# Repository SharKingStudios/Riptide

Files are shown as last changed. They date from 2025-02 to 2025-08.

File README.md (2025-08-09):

# Riptide – The Infinitely Expandable Keyboard

### My Massive Glowing Submission to Highway

---

## Renders
*Visuals because everyone loves eye candy.*

Final CAD Render Top
Final CAD Render Top Close
Final CAD Render Front Low
Final CAD Render Back
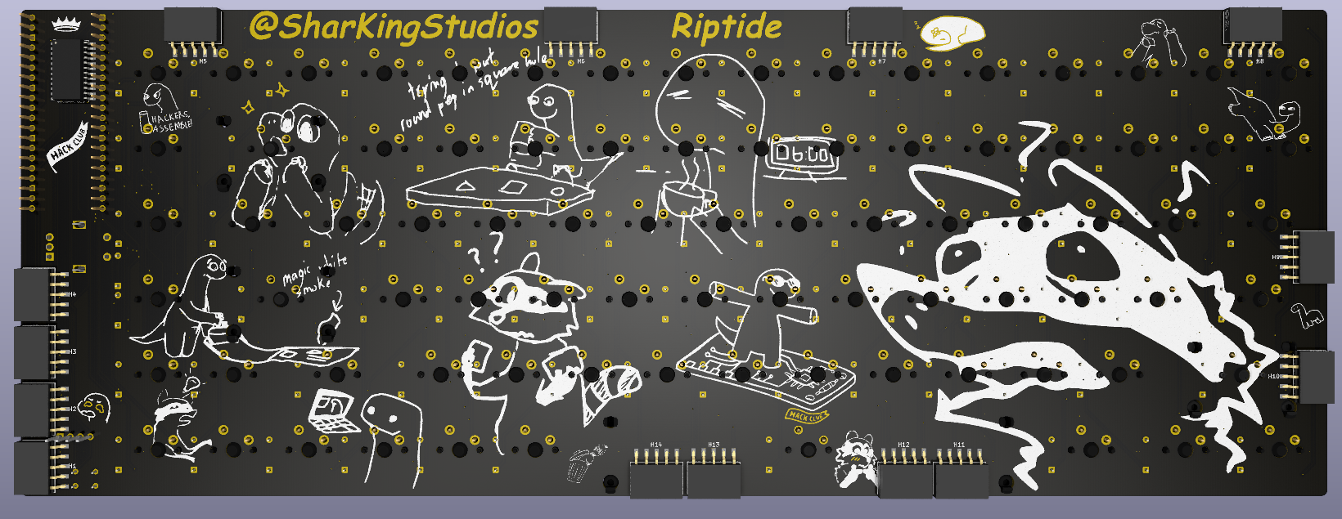
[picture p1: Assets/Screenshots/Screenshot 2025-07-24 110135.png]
Final PCB view back

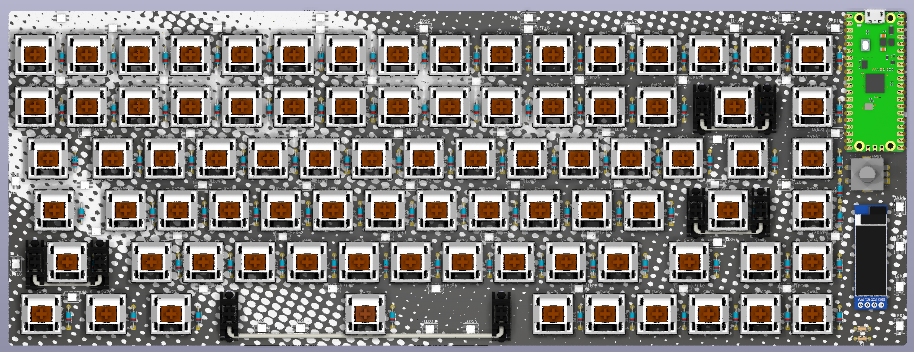
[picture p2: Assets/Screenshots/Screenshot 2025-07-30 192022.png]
Final PCB view top

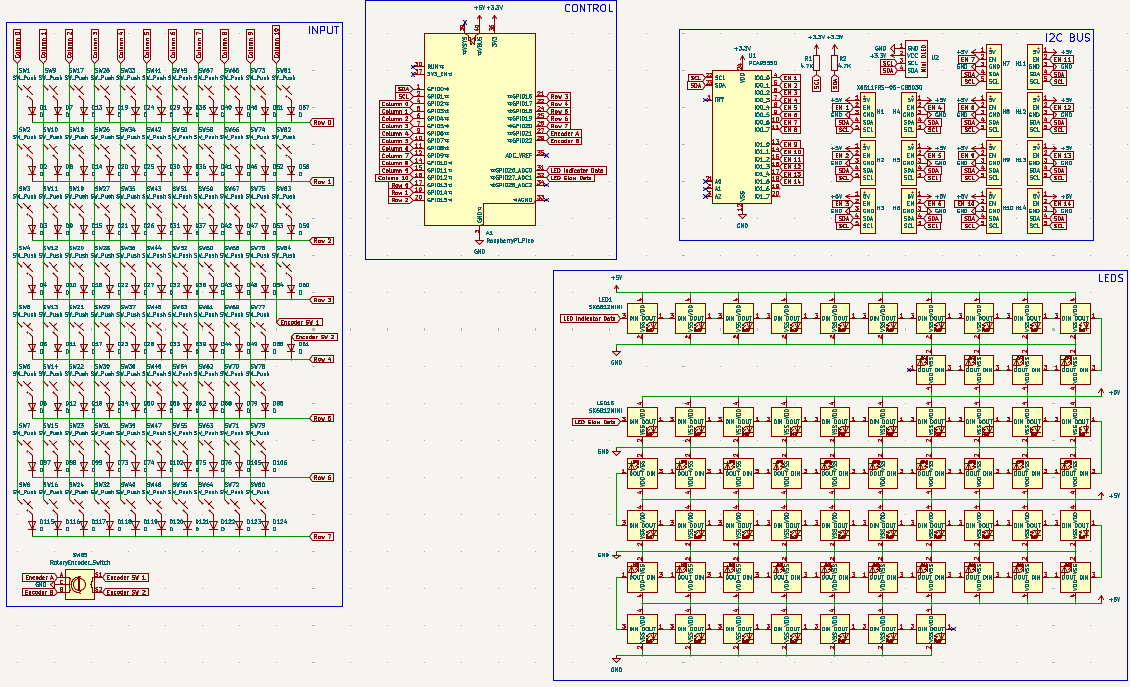
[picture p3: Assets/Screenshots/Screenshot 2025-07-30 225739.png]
Finished Schematic


---

## What is this?
It's a custom keyboard built for infinite expansion through its module ports! It uses an Orpheus Pico, QMK firmware, and even more LEDs.
The expansion modules could be literally anything! From a screen, a rechargeable battery, a buzzer, or even more LEDs! 

### Features:
- **Keycool84 Layout** – Possibly the best?
- **Rotary Encoder** – Twist for volume, scroll, or secret hacker functions.
- **Clickable Encoder Button** – Because sometimes, twisting isn’t enough.
- **61 SK6812 Mini LEDs** – ✨Almost blinding✨
- **Literally Infinite Expandability** – Custom designed module slots that support chaining submodules together!

---

## How It Works:
The infinitely expandable modules were built using an I2C bus! Also since the Orph Pico knows which modules are plugged in, certain modules could unlock further functionality from another! Like a button module being able to activate a haptic feedback (vibration) module. (This isnt built in yet // Software still WIP)

Each module slot has a 5V, EN, GND, SDA, and SCL lines.
After a module is plugged in and ready to work it will pull its EN line high to 3.3V, letting the Pico know there is something there in that expansion slot!

Final CAD Render Side

---

## Why?
I built this keyboard for [Highway](https://highway.hackclub.com)—an awesome Hack Club YSWS project mainly run by [Alex Ren](https://github.com/qcoral). (I helped run this event as one of the project reviewers!) I wanted to create something that wasnt just useful, but also super cool! Thats why I went with creating my own expansion support instead of just adding a USB hub and calling it a day.

---

## BOM
All the bits and pieces needed can be found **[here](/BOM.csv)**.

| Name | Amount | Price  | Source |
|---|---|---|---|
| PCB | 1 (5) | 33.74  | [JLCPCB](https://jlcpcb.com/) |
| Keycaps | 1 | 24.99  | [Amazon](https://www.amazon.com/dp/B0DBPKP52D?th=1) |
| Gateron Red Keyswitches| 1 | 34.99  | [Amazon](https://www.amazon.com/gp/product/B07CVQ7ZRL) |
| Gateron Clear Stabs | 1 | 11.99  | [Amazon](https://www.amazon.com/dp/B0BV2CKDJW) |
| Diodes | 85 (100) | 6.99 | [Amazon](https://www.amazon.com/dp/B079KJ91JZ) |
| 11"x14" Acrylic | 1 (2) | 11.99  | [Amazon](https://www.amazon.com/dp/B0CQYPRG4F) |
| SK6812MINI-E LEDs | 61 (65) | 3.84 | [LCSC](https://lcsc.com/product-detail/RGB-LEDs-Built-in-IC_OPSCO-Optoelectronics-SK6812MINI-E_C5149201.html) |
| PCA9555D | 1 | 1.75 | [LCSC](https://lcsc.com/product-detail/I-O-Expanders_NXP-PCA9555DB-118_C133183.html) |
| X6511FRS-05-C85D30 | 14 (15) | 2.46 | [LCSC](https://lcsc.com/product-detail/Female-Headers_XKB-Connection-X6511FRS-05-C85D30_C5142238.html) |
| 18ga Steel Plate | 1 | 0.00 | PRICE Industries |
| Orpheus Pico | 1 | 0.00 | Me |
| OLED | 1 | 0.00 | Old Hackpad Kit |
| EC11 Rotary Encoder | 1 | 0.00 | Old Hackpad Kit |
| M2.5 10mm Standoffs | 12 | 0.00 | Me |
| M2.5 3mm Screw | 12 | 0.00 | Me |
| 4.7K THT Resistor | 2 | 0.00 | Me |
| Shipping | N/A | 11.26  | LCSC |
| **Total** | — | **130.00** | — |

---

## Contribute  
Want to make it better? Open a PR, suggest a feature, or just yell at me on GitHub.

---

## Disclaimer  
This project is 100% free, open-source, and powered by **vibes**. If it breaks, explodes, or opens a black hole, **that’s on you.**

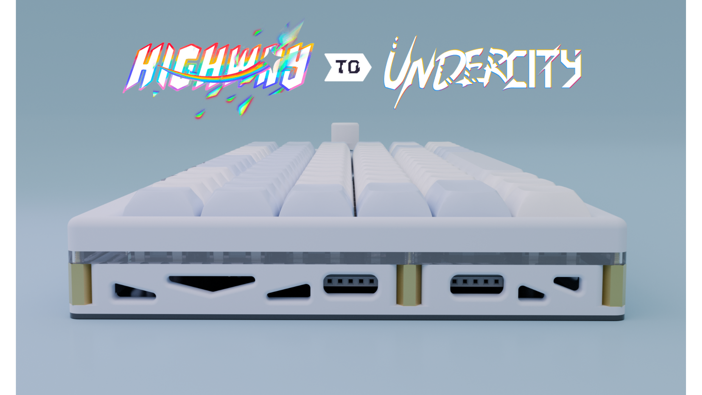
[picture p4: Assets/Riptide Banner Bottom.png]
Riptide Banner Bottom


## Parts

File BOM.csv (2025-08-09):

Name | Amount | Price | Source
PCB | 1 (5) | 33.74 | https://jlcpcb.com
Keycaps | 1 | 24.99 | https://www.amazon.com/dp/B0DBPKP52D
Gateron Red Keyswitches | 1 | 34.99 | https://www.amazon.com/gp/product/B07CVQ7ZRL
Gateron Clear Stabilizers | 1 | 11.99 | https://www.amazon.com/dp/B0BV2CKDJW
Diodes | 85 (100) | 6.99 | https://www.amazon.com/dp/B079KJ91JZ
11''x14'' Acrylic | 1 (2) | 11.99 | https://www.amazon.com/dp/B0CQYPRG4F
SK6812MINI-E LEDs | 61 (65) | 3.84 | https://lcsc.com/product-detail/RGB-LEDs-Built-in-IC_OPSCO-Optoelectronics-SK6812MINI-E_C5149201.html
PCA9555D | 1 | 1.75 | https://lcsc.com/product-detail/I-O-Expanders_NXP-PCA9555DB-118_C133183.html
X6511FRS-05-C85D30 | 14 (15) | 2.46 | https://lcsc.com/product-detail/Female-Headers_XKB-Connection-X6511FRS-05-C85D30_C5142238.html
18ga Steel Plate | 1 | 0 | PRICE Industries
Orpheus Pico | 1 | 0 | Me
OLED | 1 | 0 | Old Hackpad Kit
EC11 Rotary Encoder | 1 | 0 | Old Hackpad Kit
M2.5 10mm Standoffs | 12 | 0 | Me
M2.5 3mm Screw | 12 | 0 | Me
4.7K THT Resistor | 2 | 0 | Me
Shipping | N/A | 11.26 | LCSC
Total: |  | 130

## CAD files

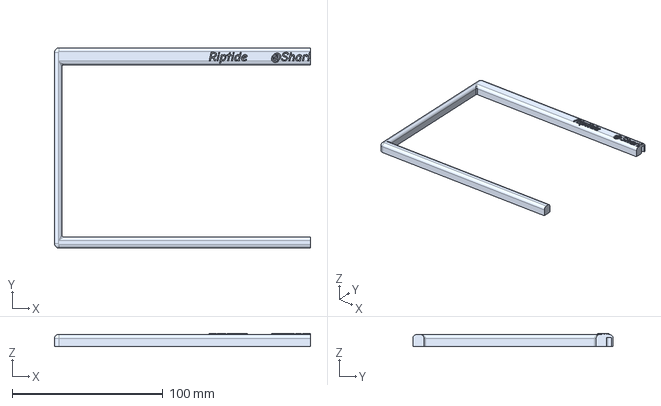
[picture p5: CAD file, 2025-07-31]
CAD/Individual Parts/Riptide Top Plate - Left.step
170.0 x 133.0 x 8.75 mm

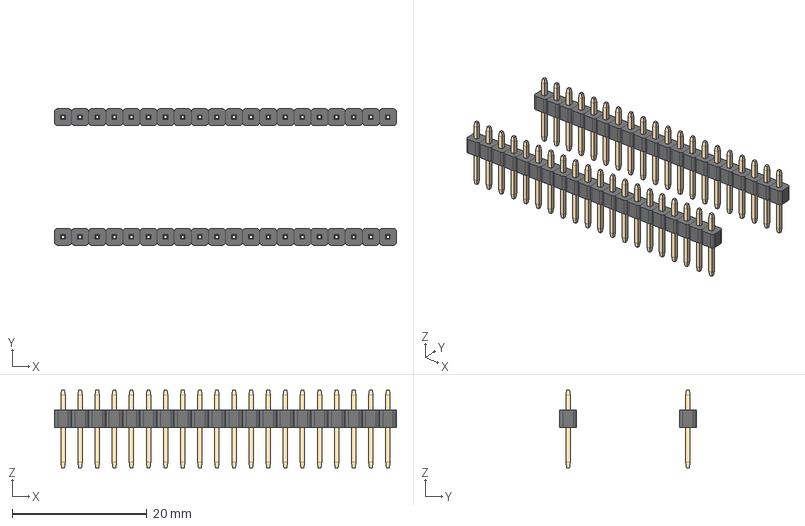
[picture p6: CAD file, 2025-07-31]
PCB/3D Models/pico headers.step
50.8 x 20.3 x 11.6 mm
spacer x 2
pins 21-40
pins 1-20

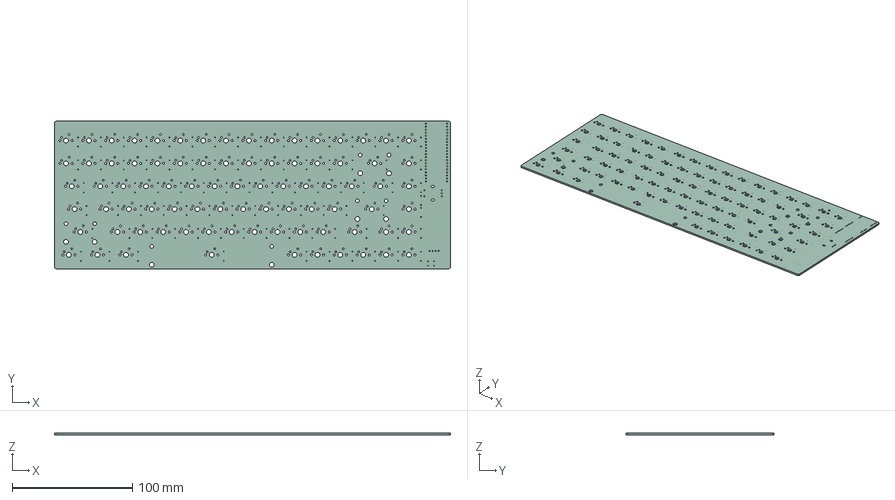
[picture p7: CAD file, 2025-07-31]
PCB/Riptide PCB Board Model v1.step
330.0 x 123.0 x 1.51 mm

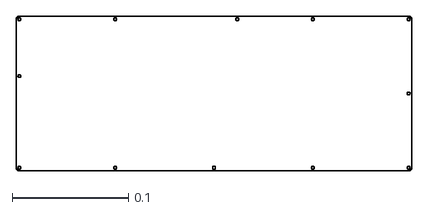
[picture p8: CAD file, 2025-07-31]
Production/Riptide Bottom Plate.dxf
0.34 x 0.133

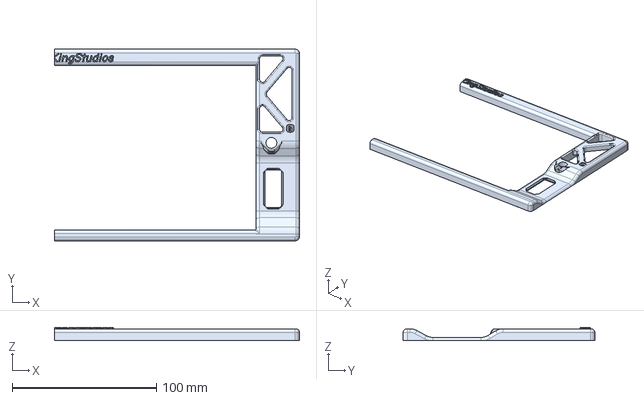
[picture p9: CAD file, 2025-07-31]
CAD/Individual Parts/Riptide Top Plate - Right.step
170.0 x 133.0 x 8.75 mm

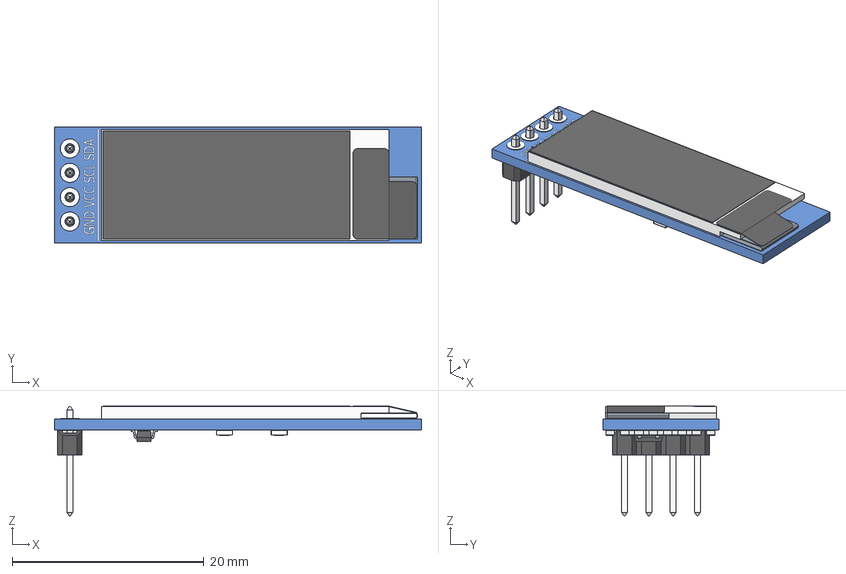
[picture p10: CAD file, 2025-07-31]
PCB/3D Models/OLED_0.91_128x32.stp
38.3 x 12.1 x 11.5 mm
OLED_0.91_128x32
Pin Header 4 x 1 TH 2.54mm Pitch
RESC-0603 x 13
2SD0601A

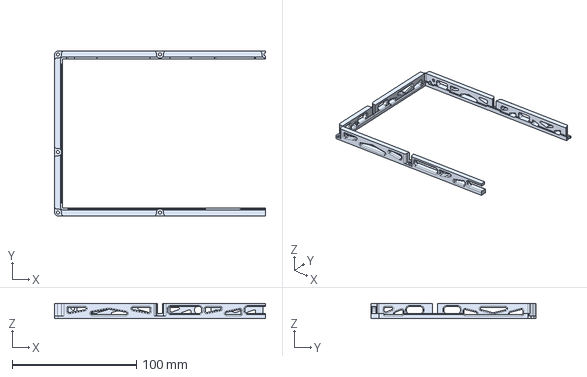
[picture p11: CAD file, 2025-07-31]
Production/Riptide Bottom Wall - Left.step
170.0 x 133.0 x 12.0 mm

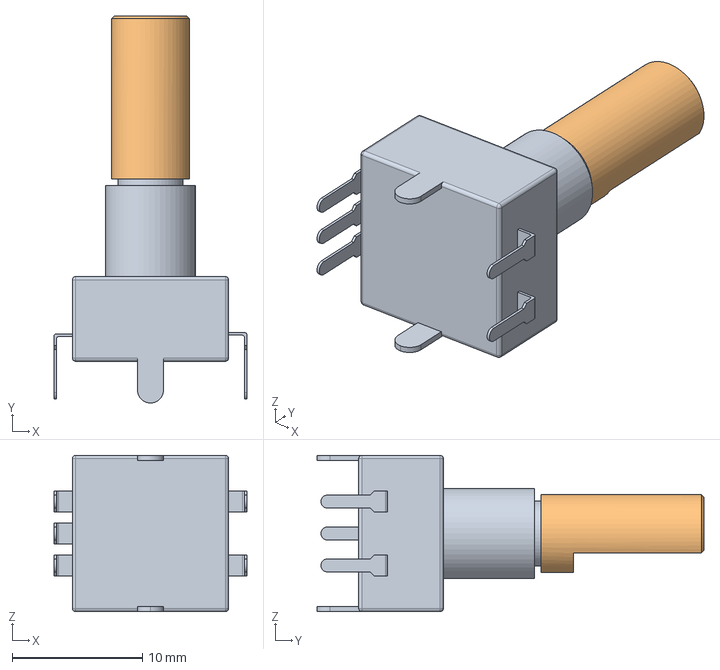
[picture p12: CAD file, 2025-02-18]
PCB/3D Models/RotaryEncoder_Alps_EC11E-Switch_Vertical_H20mm.step
14.8 x 29.7 x 12.0 mm

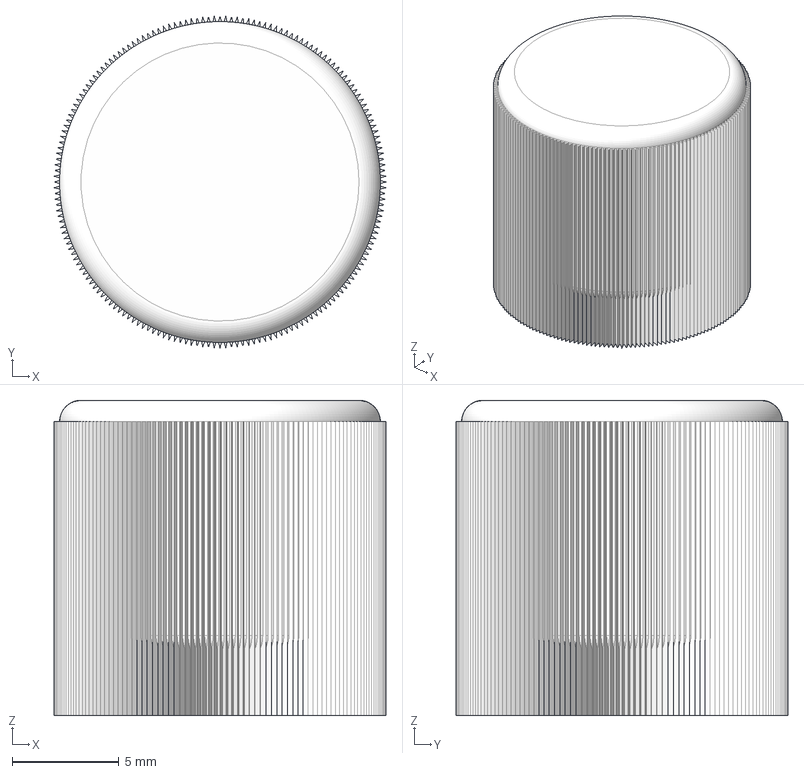
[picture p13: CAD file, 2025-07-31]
CAD/Individual Parts/Keyboard Knob.step
15.5 x 15.5 x 14.7 mm

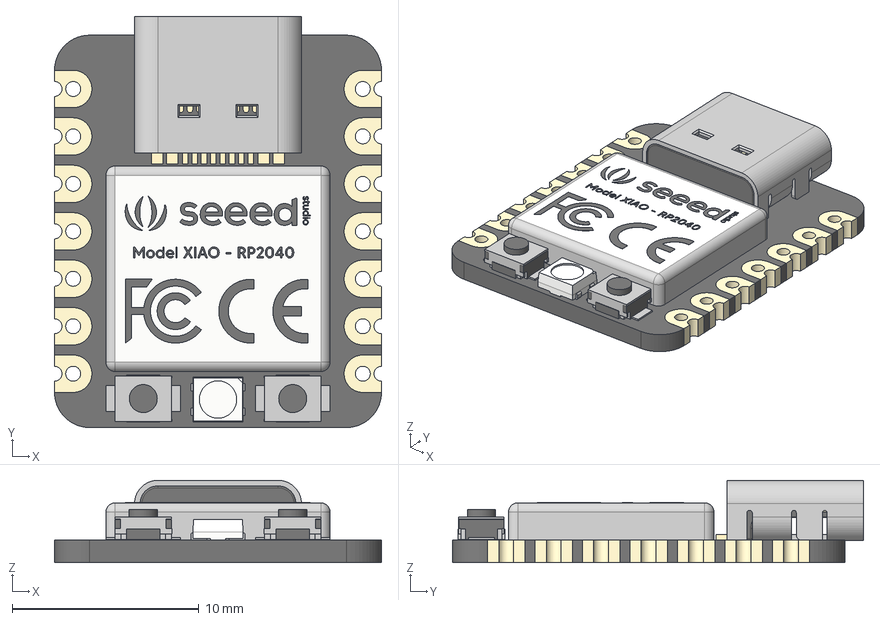
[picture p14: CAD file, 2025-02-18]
PCB/3D Models/Seeed_Studio_XIAO_RP2040_v26.step
17.5 x 22.0 x 4.40 mm
type-c v2
smd_button v3
DOUT
DIN
VSS
VDD
smd_button v3(Mirror)

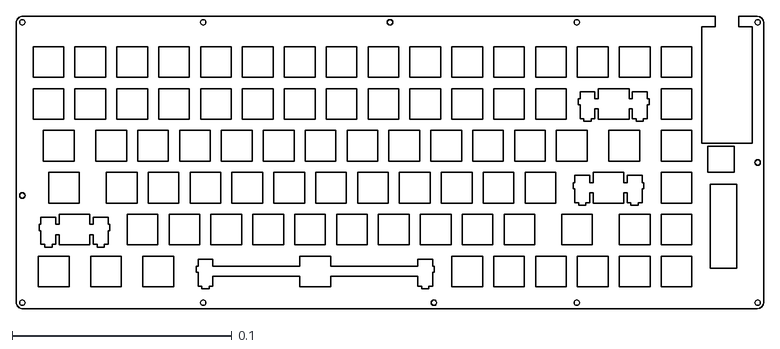
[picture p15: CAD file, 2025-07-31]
CAD/Individual Parts/Riptide Keyboard Plate.dxf
0.34 x 0.133

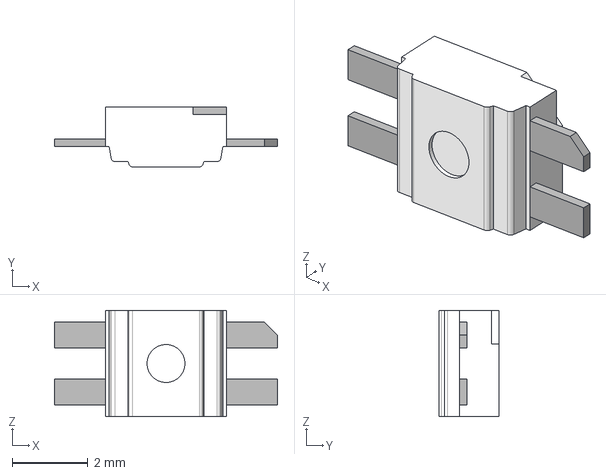
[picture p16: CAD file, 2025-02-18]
PCB/3D Models/SK6812MINI-E.step
5.88 x 1.58 x 2.80 mm

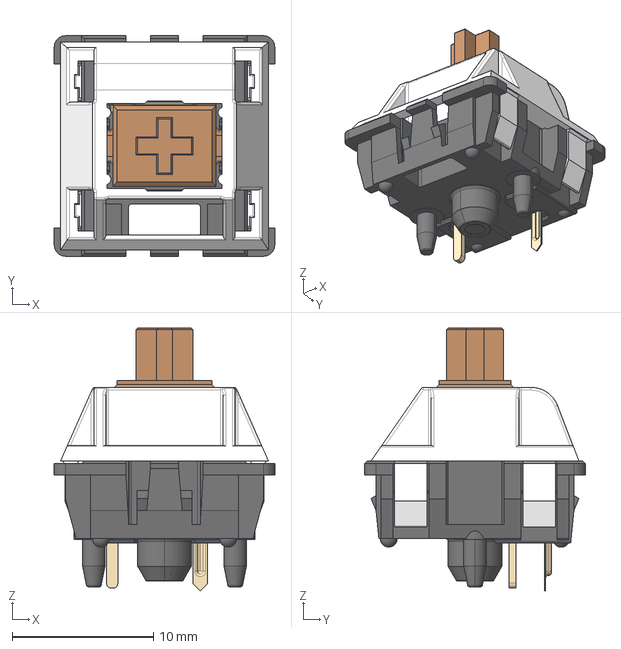
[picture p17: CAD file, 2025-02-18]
PCB/3D Models/MX_Switch.step
15.6 x 15.6 x 18.6 mm

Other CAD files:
Production/Riptide Bottom Wall - Right.step
CAD/Individual Parts/Riptide Bottom Wall - Right.step

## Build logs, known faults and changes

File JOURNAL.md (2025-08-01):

---
title: "Riptide"
author: "Logan Peterson"
description: "An Infinitely Expandable, Ocean Inspired Keyboard."
created_at: "2025-07-01"
---

**Total time Overall: 37h**

# June 1st: Started work on keyboard layout and matrix

Today I just researched a bit into the different keyboard layout types. I wanted to keep the layout similar as my current (membrane) keyboard.
I chose to use the Keycool84 layout as seen in the layout editor:

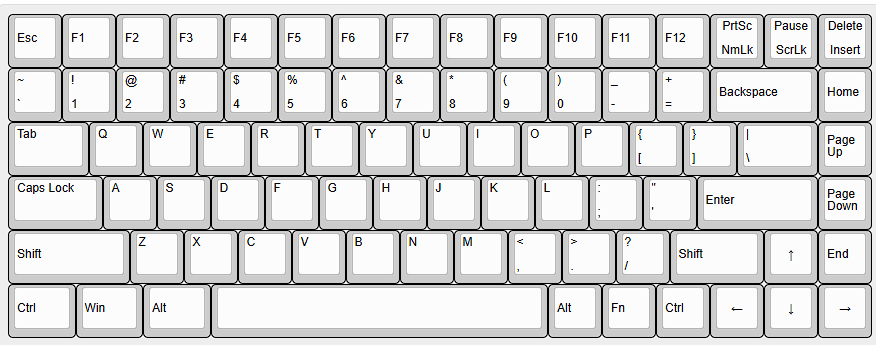
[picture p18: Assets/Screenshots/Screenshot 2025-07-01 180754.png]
Keycool84 layout


I also grabbed an old keyboard matrix I made when I was working on a keyboard prior to this. (This is about as far as I got lol)
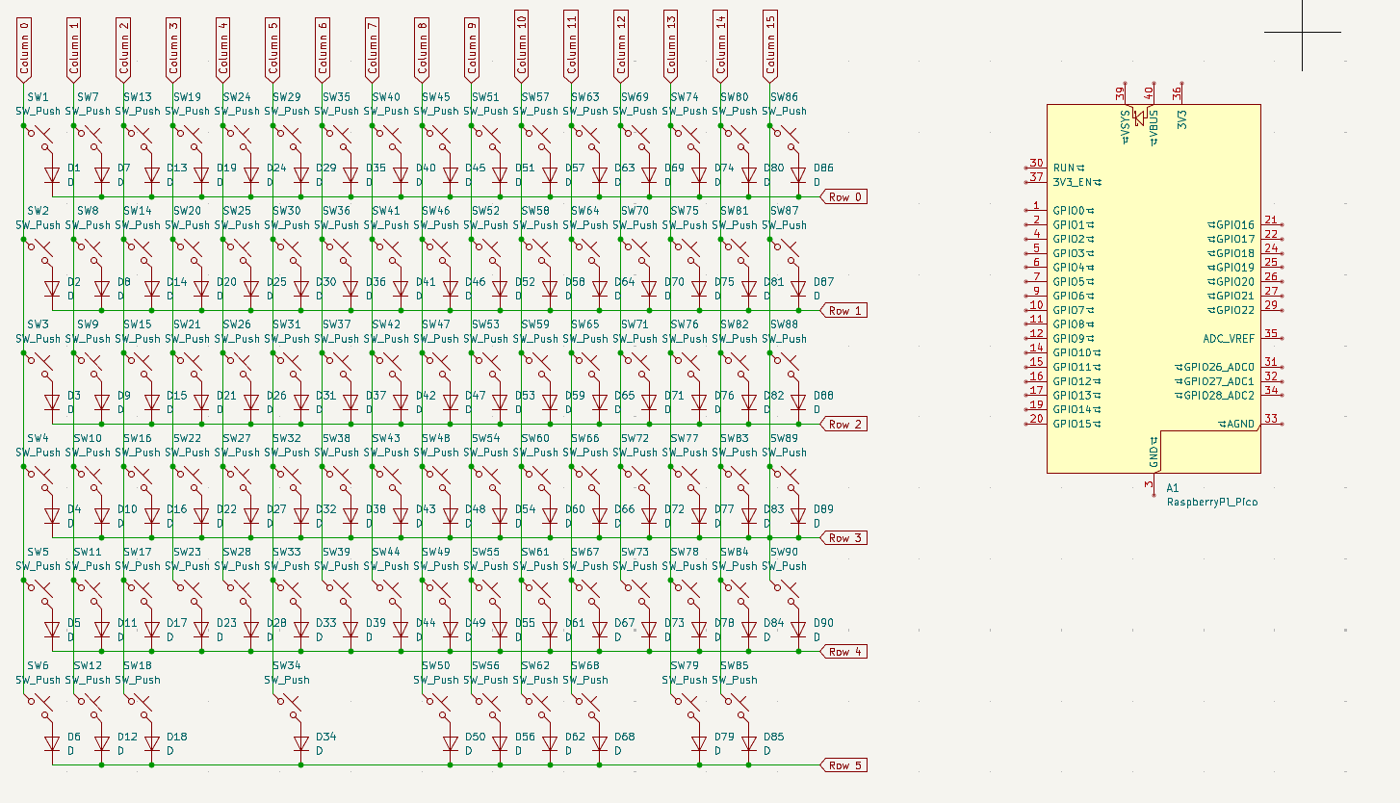
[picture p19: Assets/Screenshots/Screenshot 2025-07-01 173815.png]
old stuff


**Total time spent: 1h**

# June 2nd: Fixed the keyboard matrix

Today I fixed up the keyboard matrix to have it match my Keycool84 layout that I chose.
When I tried "fixing" it for the first time I actually added even more keys lol:

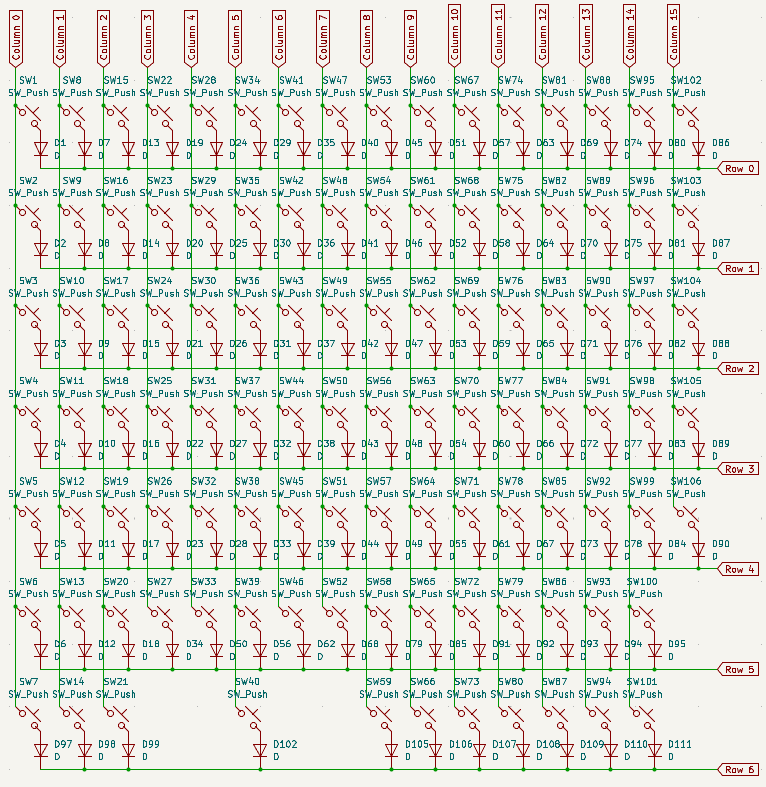
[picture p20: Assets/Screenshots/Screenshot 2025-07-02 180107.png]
not fixed lol


At first I was trying to create the keyboard matrix based of of the physical location of the keys.

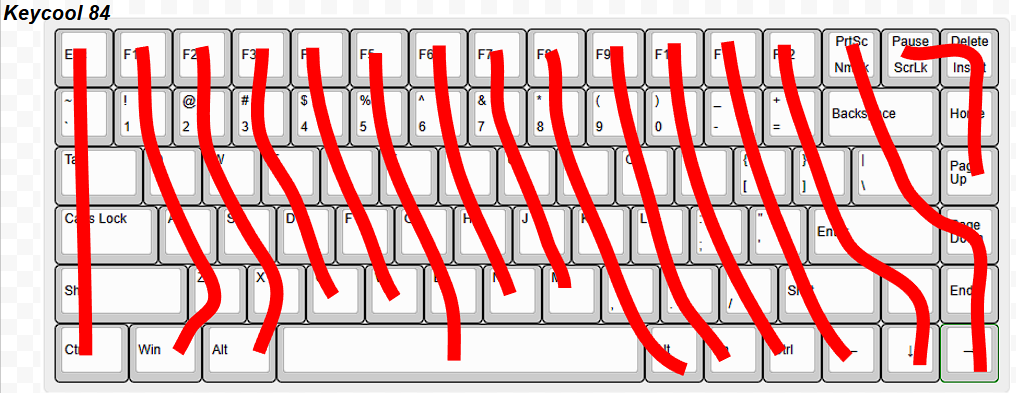
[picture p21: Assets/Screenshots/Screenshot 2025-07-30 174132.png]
Google drawings my beloved

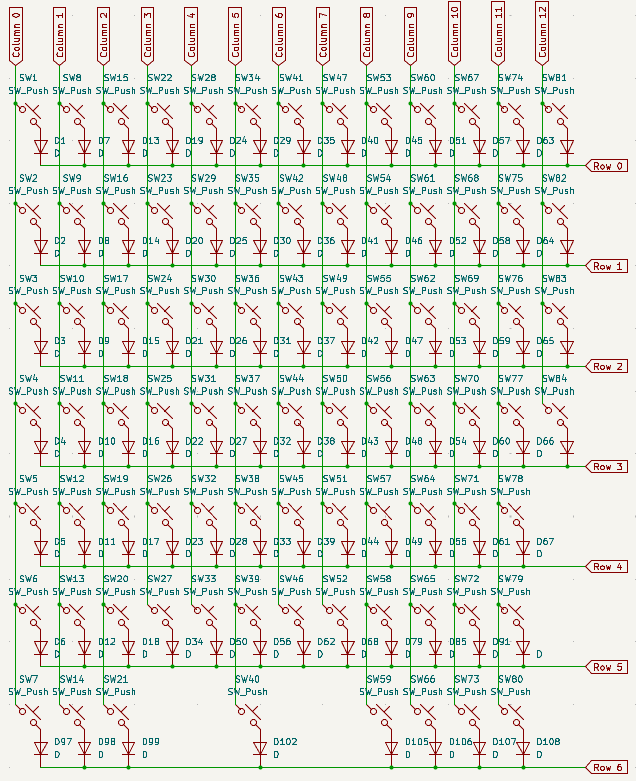
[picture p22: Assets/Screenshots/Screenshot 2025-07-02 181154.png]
Almost fixed


I then realized that since the keyboard layout editor would export the matrix data, I could make it much smaller.

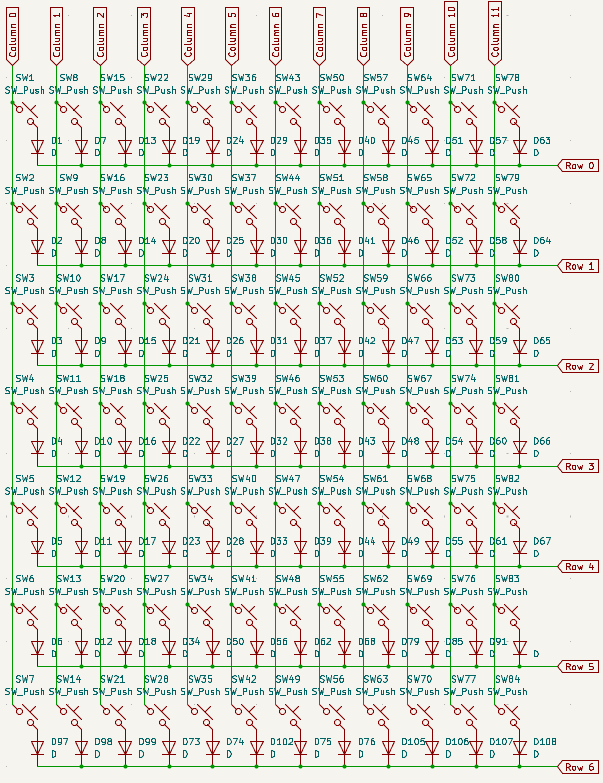
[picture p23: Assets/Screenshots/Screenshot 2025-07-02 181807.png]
Smol layout (11x8)


**Total time spent: 3h**

# June 3rd: LEDs and Infinite Expandability Support

Today I worked on putting together the LEDs in the schematic, wiring the pico to the keyboard matrix, as well as figuring out how I wanted to do the infinite expandability.

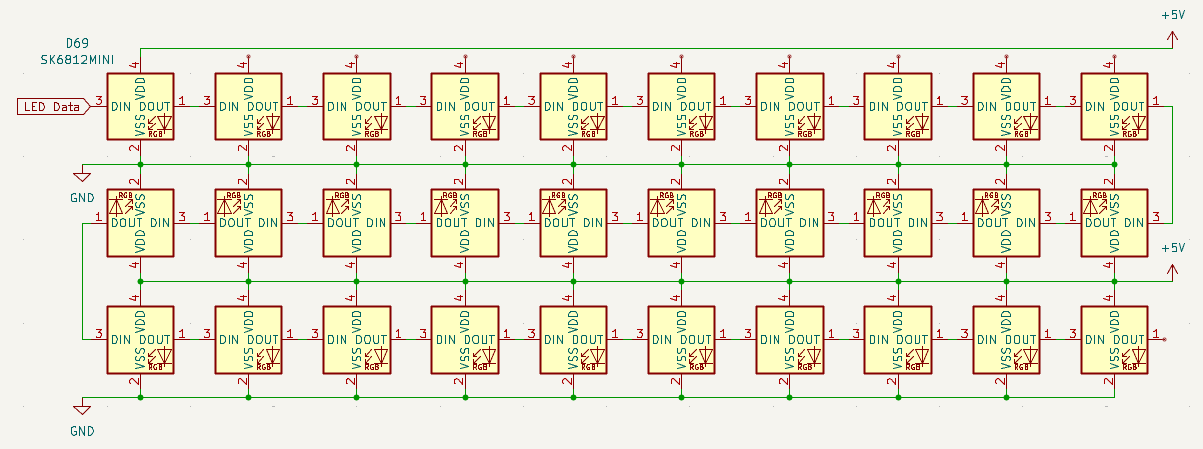
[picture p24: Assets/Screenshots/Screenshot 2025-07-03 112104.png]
LED Chain

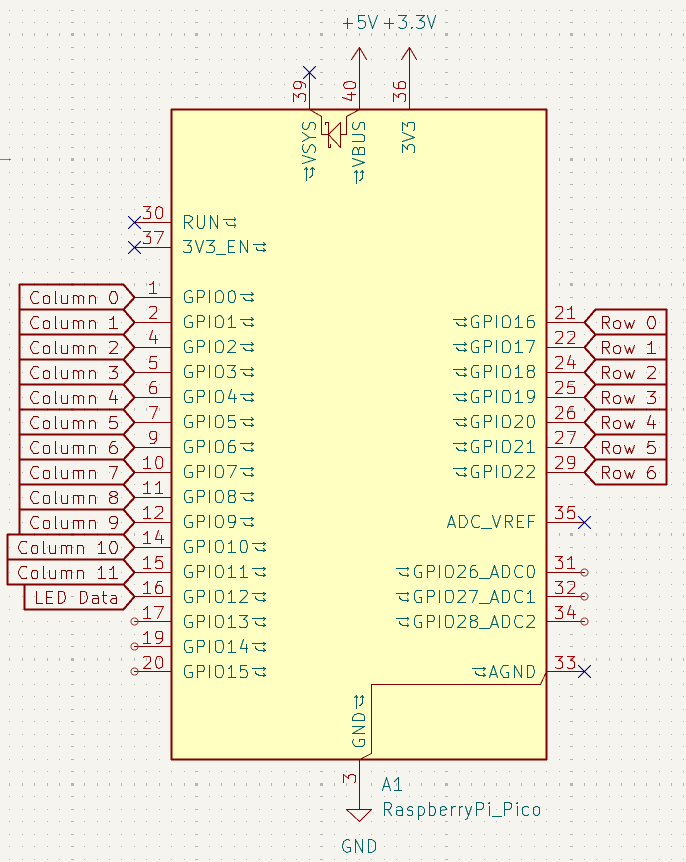
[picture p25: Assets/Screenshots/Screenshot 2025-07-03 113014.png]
Pico


So I want to have 5 pins for each module. 5V, EN, GND, SDA, SCL
I am planning on having the EN pin return 3.3V when the expansion module is ready. By having a EN pin for every module, I would be able to know which port I was plugging the module into. I am thinking this can give me some nice control and possibility for animations when you connect a module in a specific spot. (Like a wave emminating out from that port using the LEDs etc).
Anyways, the I2C bus seems like a fairly robust option considering you can use it with breadboard components, so it should be more then fine to route across my keyboard to the various module slots.

Since I would run out of GPIO pins if I gave the number connectors I wanted their own EN pin and since I already had an I2C bus, I decided to use a I2C GPIO expander to handle the EN pins. This also set my number of expansion slots at 16. (theres literally no reason to have this many lol // dear god I could put them in a matrix to have 64 slots)

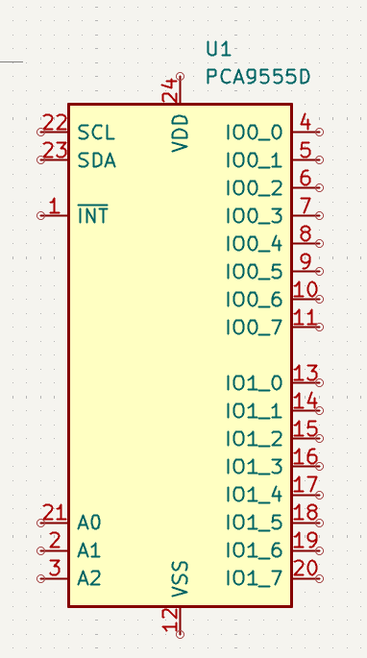
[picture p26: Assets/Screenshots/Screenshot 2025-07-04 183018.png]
I2C GPIO expander


**Time spent up to this point: 2h**

I then wanted to find a component that would work well for connecting the keyboard to the modules. I really wanted to have magnets integrated into the components to make hot swaps easier. While I could have used a 6 pin USB connector that would have looked pretty lame and someone would have plugged a USB drive into it hoping it would have worked. I actually spent a couple of hours on LCSC going through quite literally every single 5 pin 3 pin and 4 pin magnetic connector but all I found was this component here:

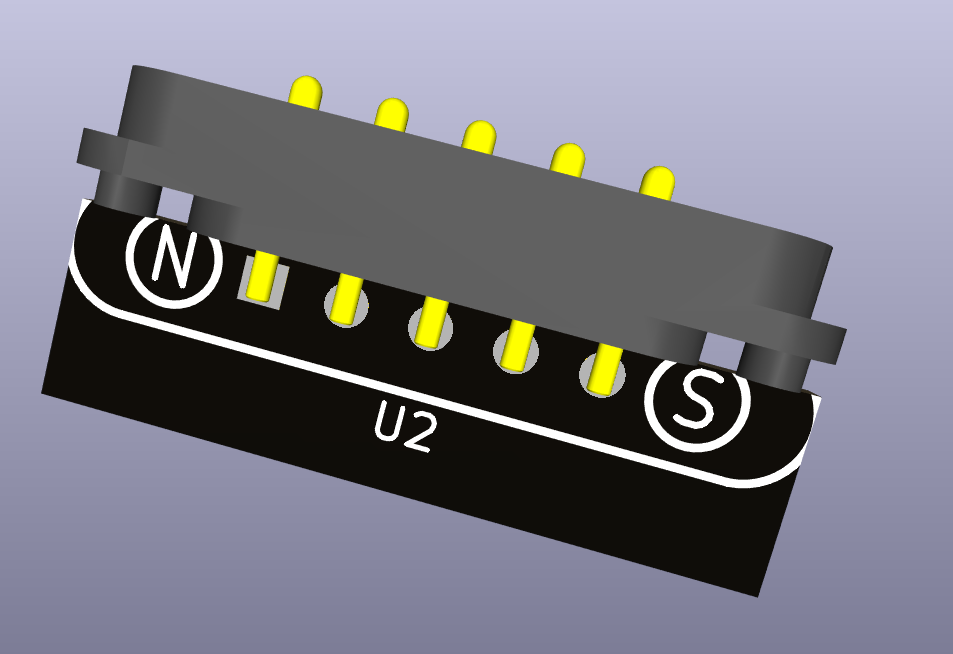
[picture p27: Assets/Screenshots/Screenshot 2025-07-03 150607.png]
Sketchy connector top view

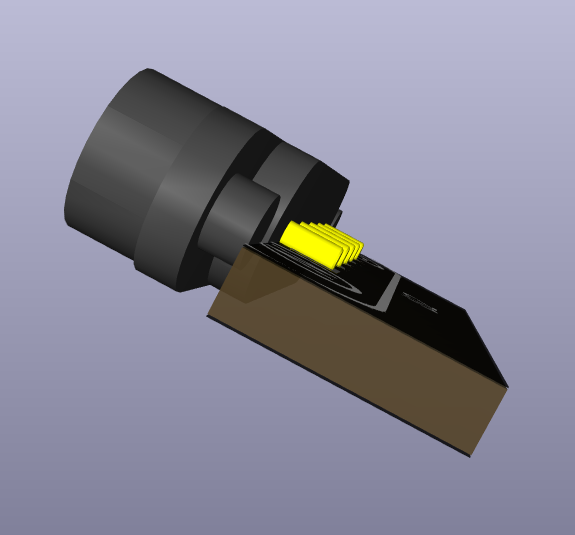
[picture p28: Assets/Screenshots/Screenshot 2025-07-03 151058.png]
Sketchy connector side view


(I manually rotated it onto its side)

Anyway I thought this would be too sketchy so I left that idea and went to the good ol reliable:

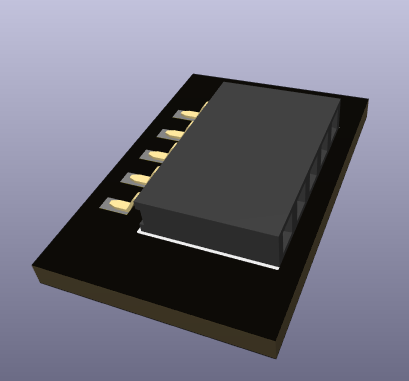
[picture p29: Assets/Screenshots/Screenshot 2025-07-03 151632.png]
Normal Female 2.54 header


After I figured out my connector footprint I put together a layout for my PCB (w.o. LEDs):

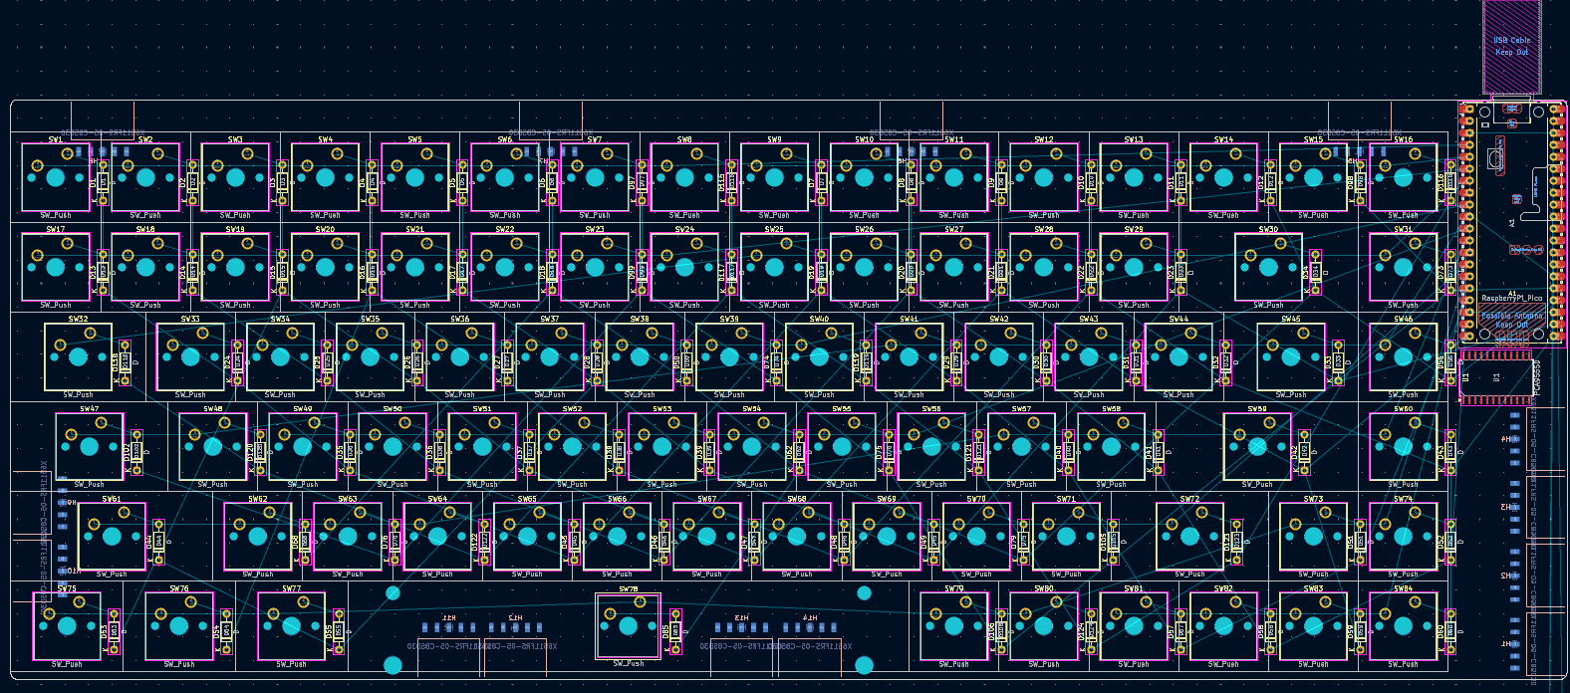
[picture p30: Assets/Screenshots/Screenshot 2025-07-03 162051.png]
Initial PCB layout


**Time wasted on connectors: 3h**

# June 5th: Laying out LEDs + Encoder and OLED

Today I layed out the LEDs into my PCB as well as adding an Encoder and an OLED.
I started the LED placement with the 14 LEDs that would act as status LEDs for any connected module:

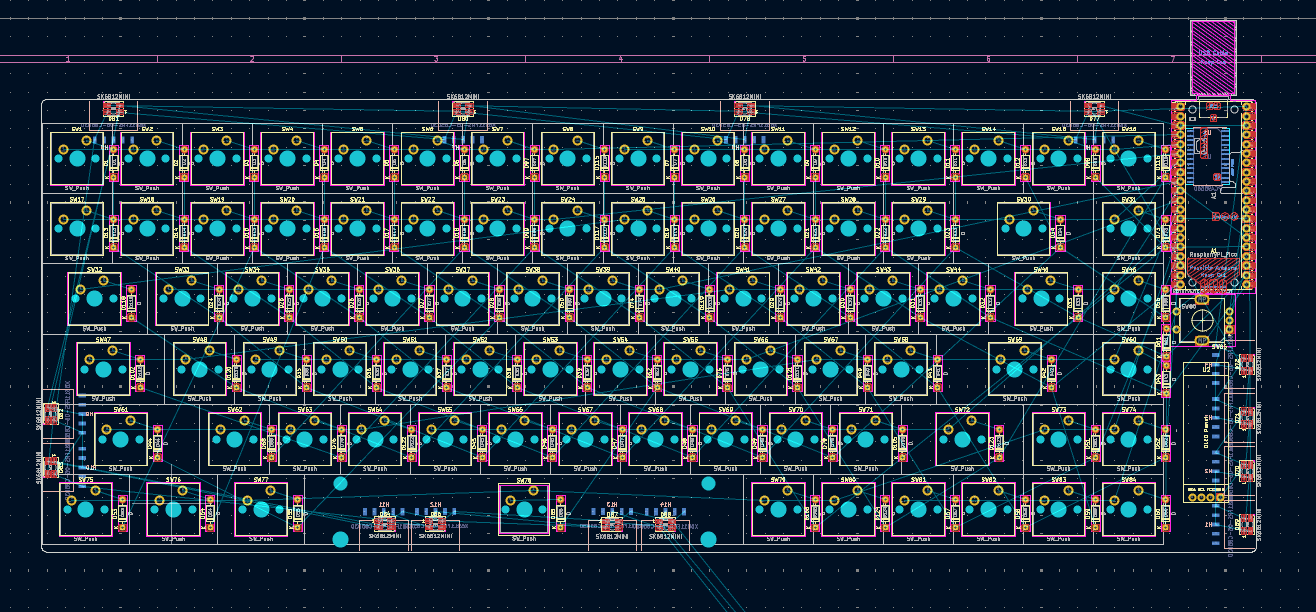
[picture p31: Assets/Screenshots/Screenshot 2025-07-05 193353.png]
Indicator LEDs in place


I also added even more LEDs that I would place around the keyboard and structured them into 2 data lines (I am hoping this makes programming the specifics easier).

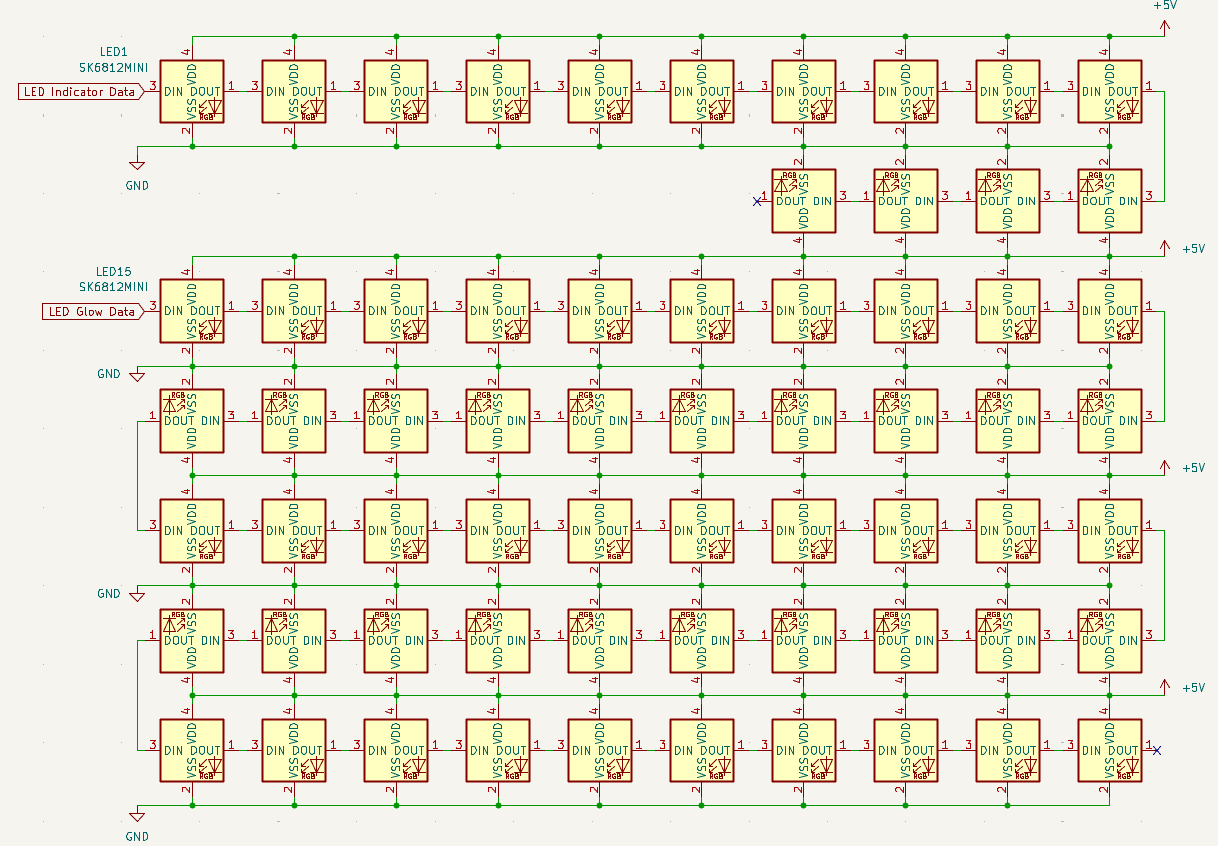
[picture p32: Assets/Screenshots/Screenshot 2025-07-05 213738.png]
Even more LEDs


After that I wired up all of the module slots in the schematic:

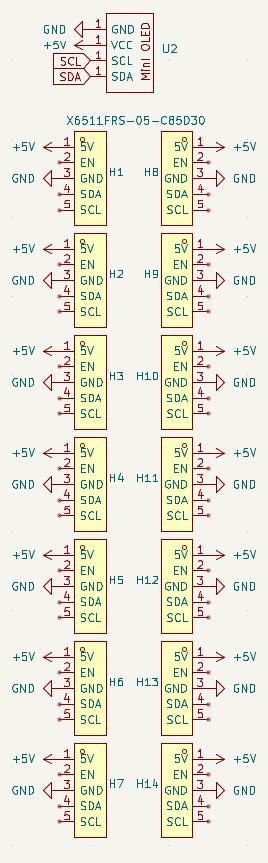
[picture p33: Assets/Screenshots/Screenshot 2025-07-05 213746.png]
Meh formatting


Then changed it to have better formatting:

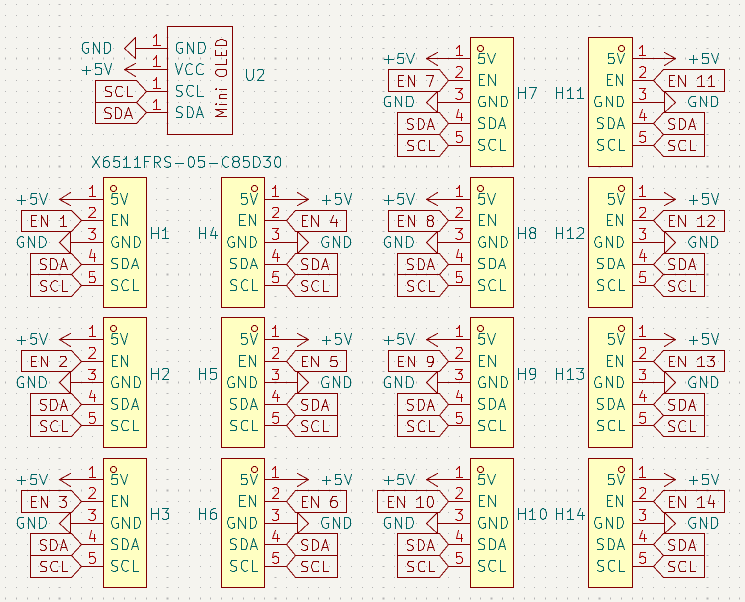
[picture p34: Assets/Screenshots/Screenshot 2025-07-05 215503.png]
Better formatting


And that finishes the schematic:

Finished Schematic

I then counted the spaces for where I wanted LEDs to go (checked it twice lol so 2 dots):

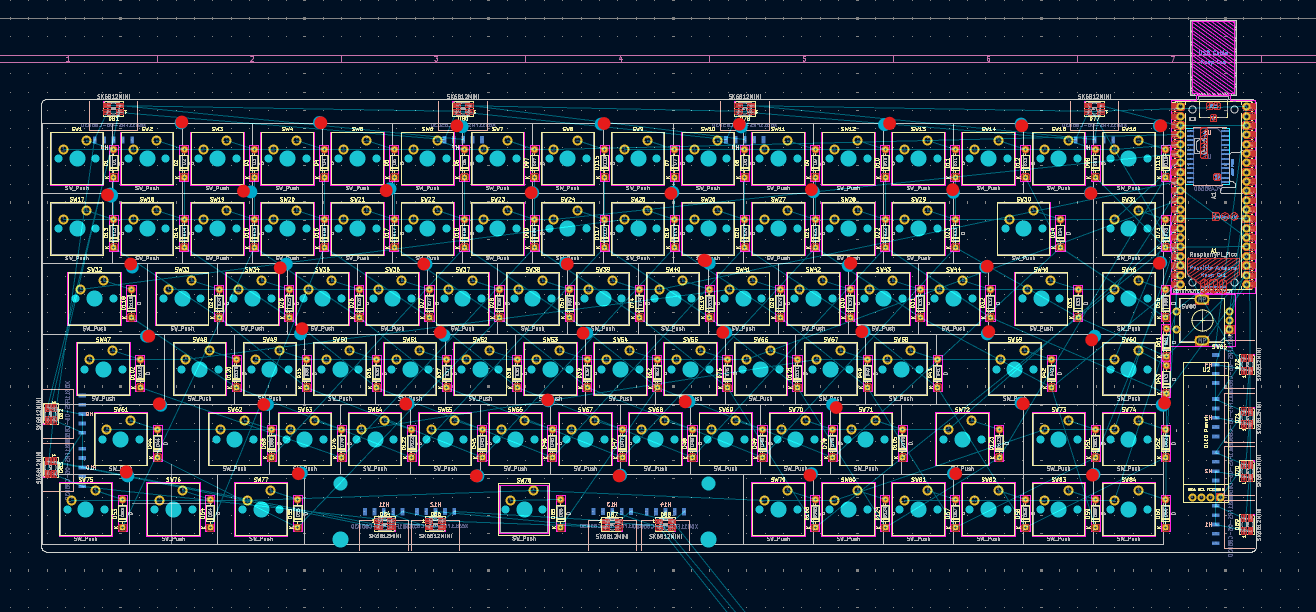
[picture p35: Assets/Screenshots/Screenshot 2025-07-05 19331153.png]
Marked spaces for LEDs


After that I added in all the keyboard LEDs:

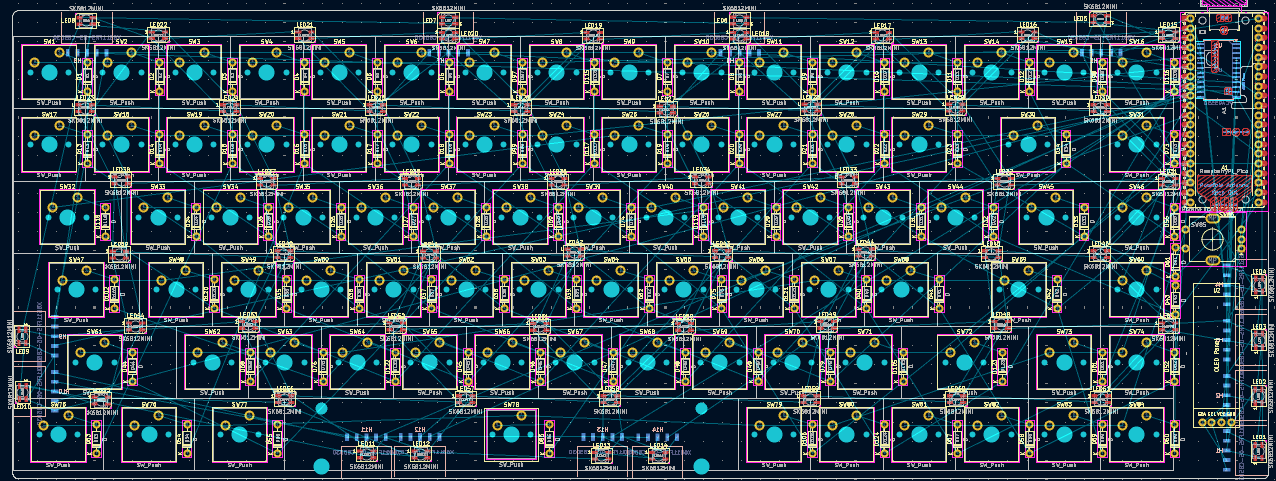
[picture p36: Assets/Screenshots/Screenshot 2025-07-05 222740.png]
All keyboard LEDs


**Total time spent: 2.5h**

# June 6th: Routing Time

I started routing today (*yippie*). I tried using .6mm to route everything then just switched back to .4mm lol
I also added some 4.7k pull up resistors on the I2C lines because I forgot those earlier.
After this I also added every 3D model. (Cant have a bare render right??)

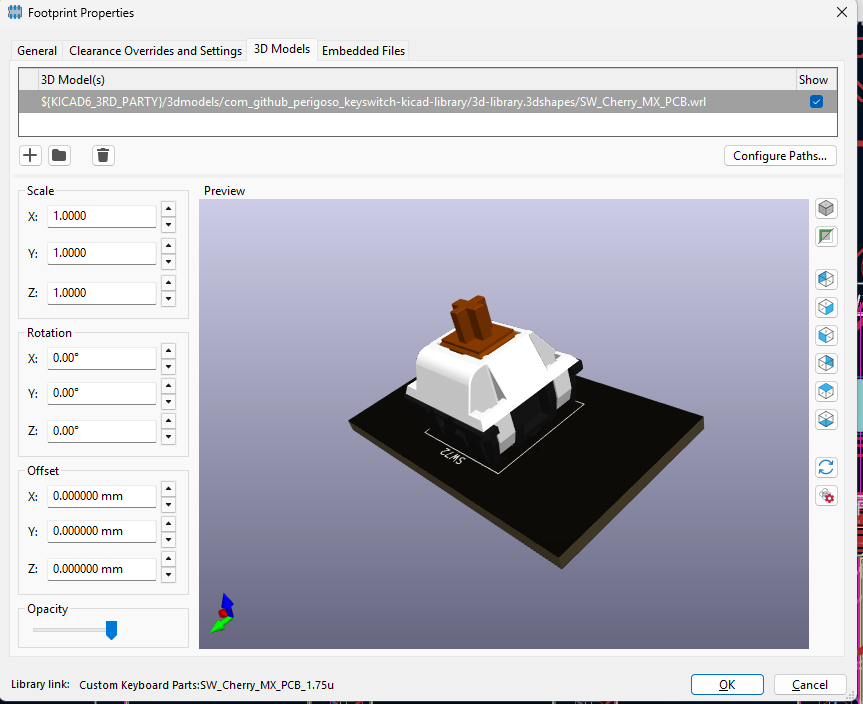
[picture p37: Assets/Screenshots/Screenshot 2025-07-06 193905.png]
Adding 3D models


After routing ***the entire thing*** I realized I forgot to add the all important stabiliers on the shift key, enter key, and backspace.
When I did add them I needed to redo some wiring but they also interfered with multiple items including various LEDs and some of the expansion ports:

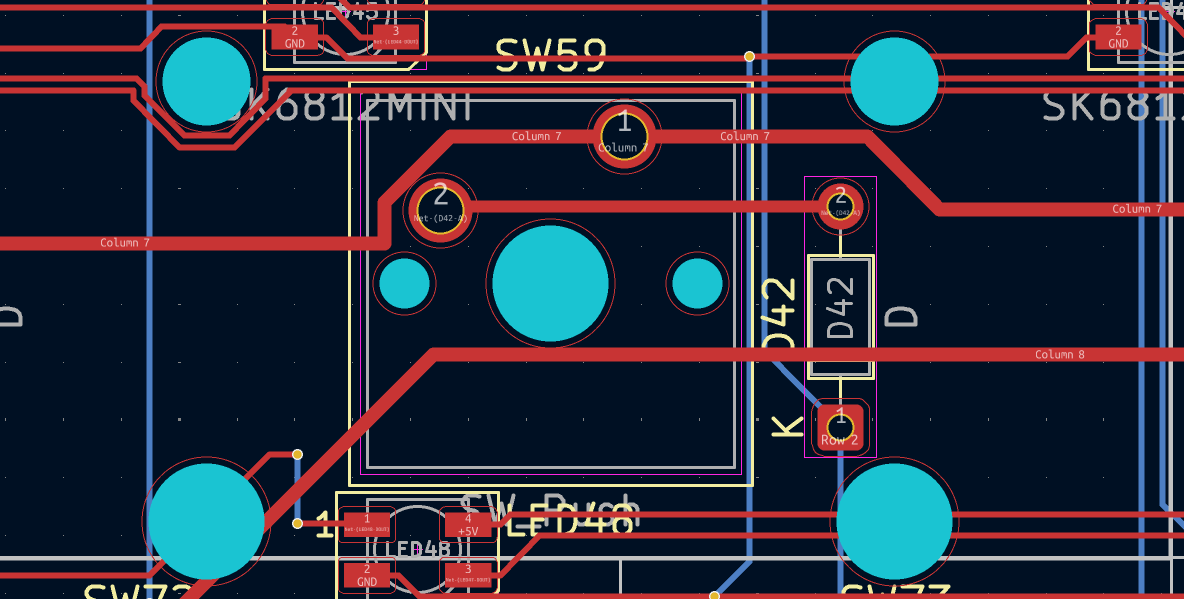
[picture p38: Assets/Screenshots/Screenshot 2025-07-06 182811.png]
Wires getting cut off

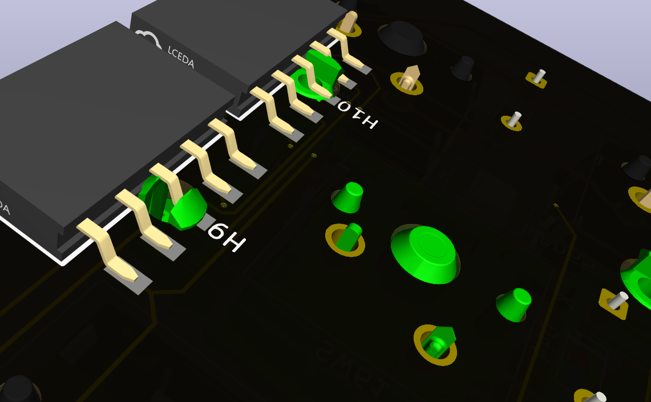
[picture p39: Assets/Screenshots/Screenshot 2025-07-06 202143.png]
Other parts getting cut off


After I finished all of the issues with the PCB I finally got this:

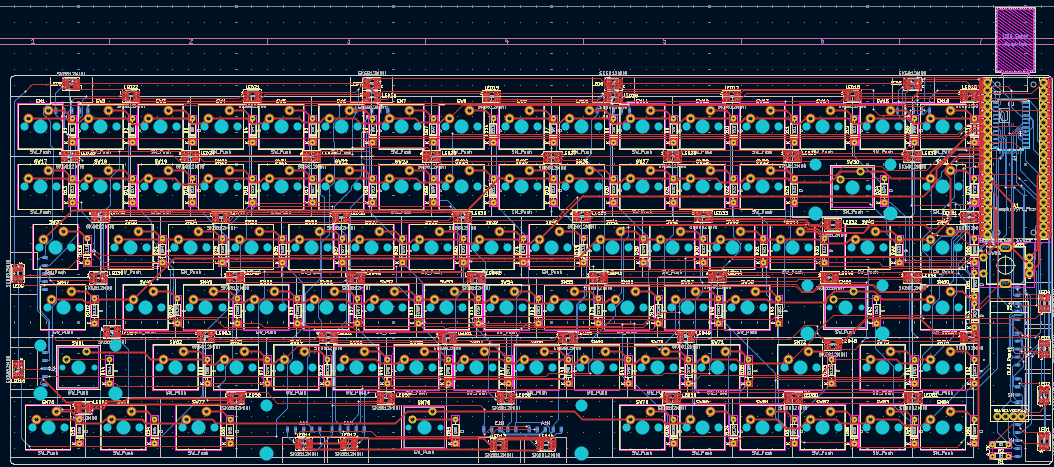
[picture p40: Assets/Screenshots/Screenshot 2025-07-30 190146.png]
Finalized PCB trace routing

No DRC errors

**Total time spent: 7h**

# June 24: We are so back! (From Undercity lol)

Undercity was super fun!! I loved helping run such a big event!
Anyways, this is me after I finished up with the rereviews that were waiting for me during undercity...

Today I worked on the PCB art for the keyboard. 
I got this nice wavy pattern in for the front:

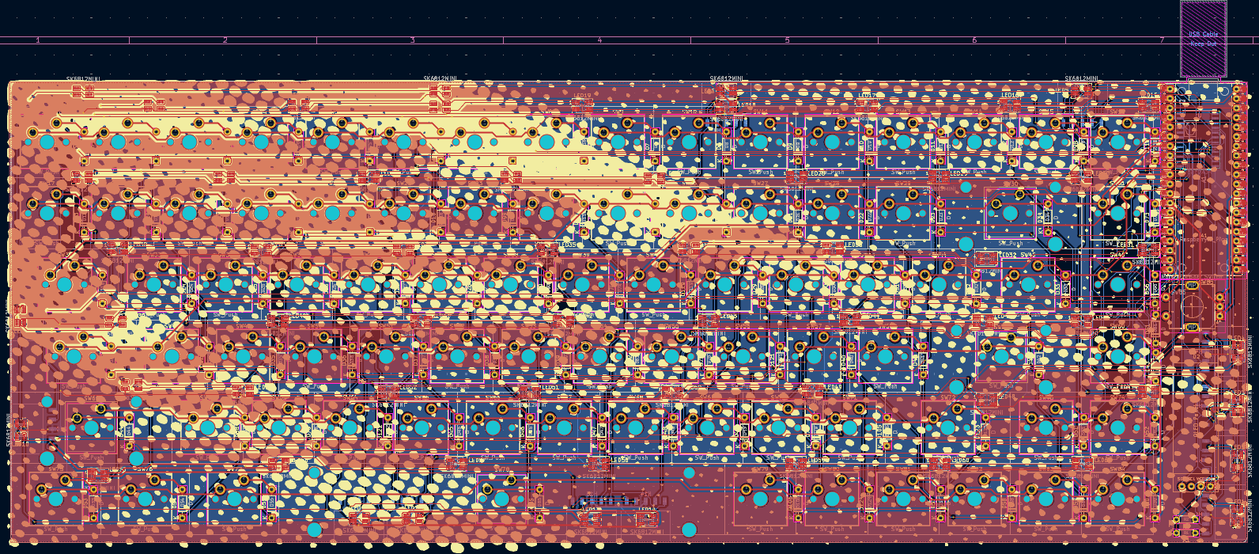
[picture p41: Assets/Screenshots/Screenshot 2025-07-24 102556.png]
PCB editor view front


and used my collection of silkscreen art for the back (mostly from rawr.hackclub.com):

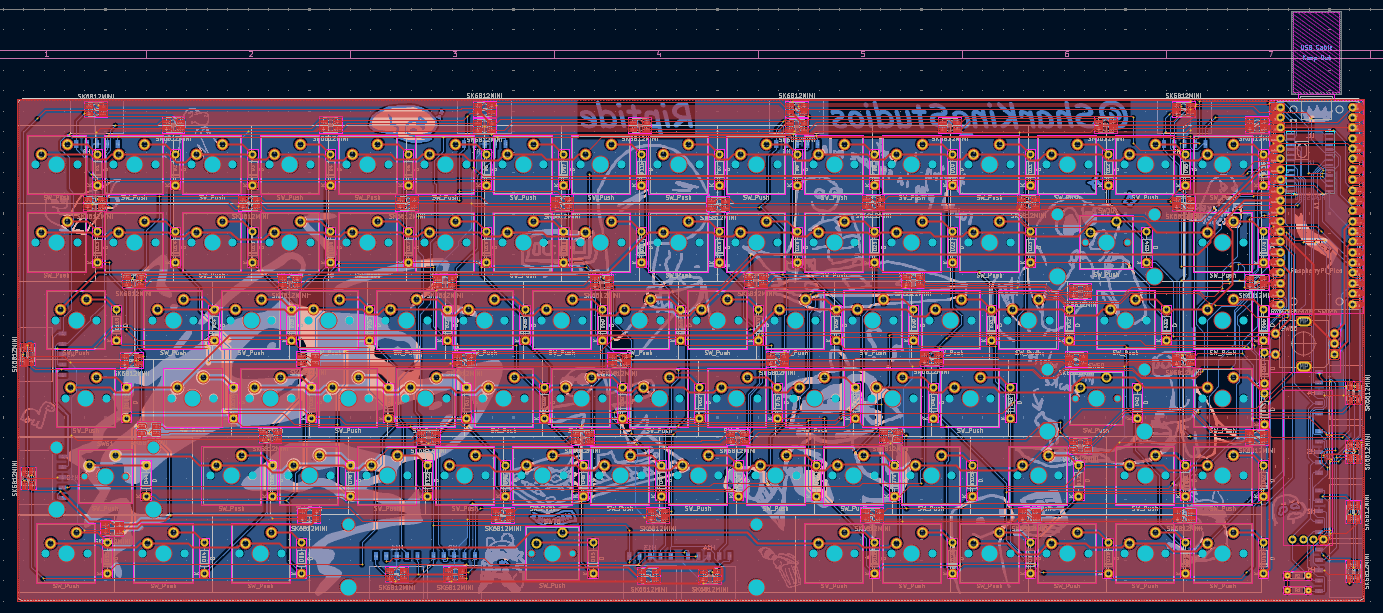
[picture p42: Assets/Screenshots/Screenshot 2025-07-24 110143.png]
PCB editor view back


Final product:

Final PCB view top
Final PCB view back
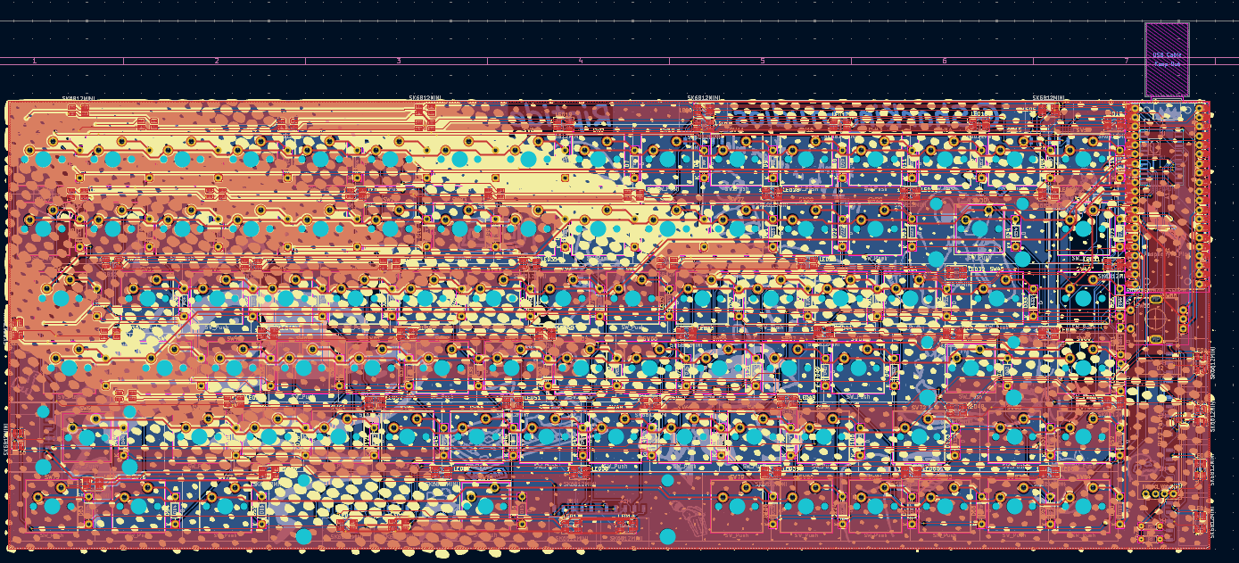
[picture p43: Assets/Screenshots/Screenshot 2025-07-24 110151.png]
Final PCB editor view


I even totally got no DRC errors!!

No DRC errors
Ignored errors (8)

**Total time spent: 2.5h**

# June 28: CAD time

Today I got my Onshape set up with files from my KiCAD and started work on the case.
I spent an especially long time working on getting every single keycap in the CAD. (To make it look awesome ofc)

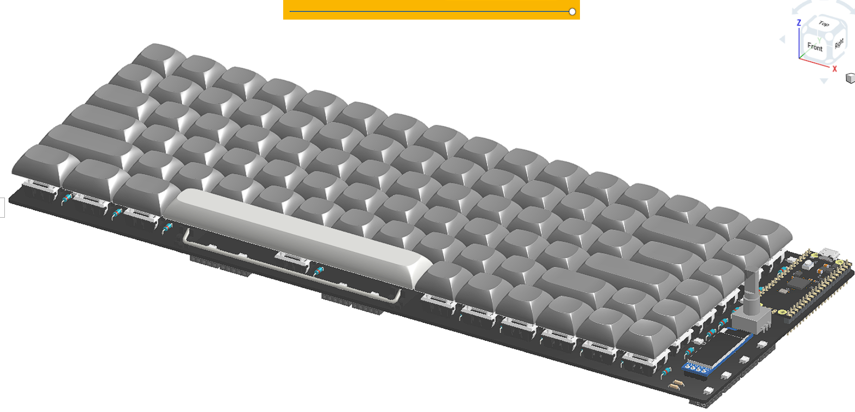
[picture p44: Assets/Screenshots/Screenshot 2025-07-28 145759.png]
Start of CAD

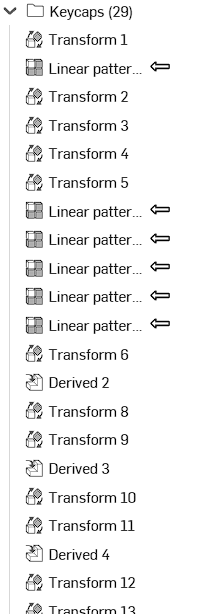
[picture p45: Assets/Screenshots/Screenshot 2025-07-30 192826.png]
My God why are there so many edits just for keycaps


After I got the keycaps in place I created a keyboard plate as well as the 3D printed top section that would hold it down.
I wanted to use a similar style to my Splashpad and keep the awesome looking Orpheus Pico visible.

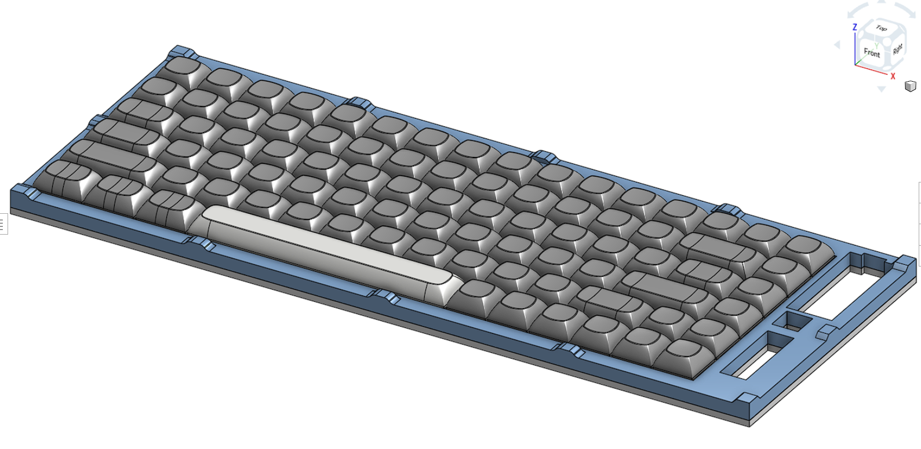
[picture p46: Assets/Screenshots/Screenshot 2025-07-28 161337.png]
Meh Top Plate


I didnt like the way it was turning out so I changed it to this:

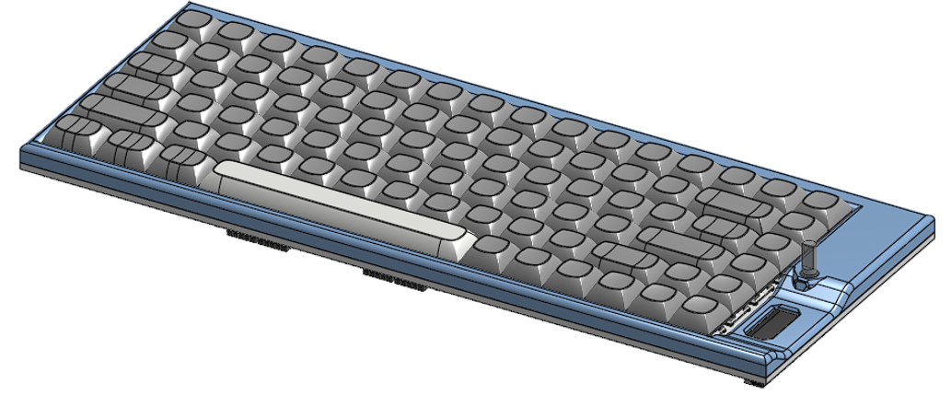
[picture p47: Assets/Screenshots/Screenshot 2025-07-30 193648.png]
Better Top Plate


I then finished the day by adding bronze standoffs that I had lying around from a previous project and a 18ga steel bottom plate:

Nice Bottom (Plate)

**Total time spent: 5h**

# June 30: Finished the CAD

Creating the middle section was kinda the hardest part of the CAD. Its also what really pulled this keyboard together (almost literally). It does look truely awesome though.

WIP:
CAD WIP

When making the isogrid pattern I followed the same kind of procedure I used with my Splashpad.
I finished it up by changing all the keycaps to the colors they would be with the set I intend on using.

Final CAD:
Final CAD Render
Final CAD Render Top

**Total time spent: 6h**

# June 30: Magic Keyboard Firmware

When I had made my Riptide hackpad, I used KMK firmware for its ease of use as I thought it would be easier.
After I built it, I have been having significant trouble getting it to work. Instead for the keyboard I have decided to use QMK firmware.

Making the firmware actually wasnt as hard as I thought it would be since I already had Ubuntu Linux installed in my terminal.

I did experience a number of errors:

Compile error

But I was able to get it compiled:

Compiled yay

**Total time spent: 1h**

# June 31: Blender my Glorious Goat

I dont know blender but I really want some nice visuals.
Time to learn it ig.

It actually wasnt too bad, except how after I exported from my CAD the keyboard had a bajillion assigned materials that I had to go through.
The extent of my lighting knowledge is to have a Key, Fill, and Ring.

Working Screenshots:
Working 1
Working 2
Working 3
Working 4
Working 5

I was able to make some totally awesome looking renders:





**Total time spent: 4h**

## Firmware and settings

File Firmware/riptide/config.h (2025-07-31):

#pragma once

#define VENDOR_ID       0xFEED
#define PRODUCT_ID      0x1337
#define DEVICE_VER      0x0001
#define MANUFACTURER   "Logan_Peterson"
#define PRODUCT        "Riptide"

#define MATRIX_ROWS 8
#define MATRIX_COLS 11

#define MATRIX_ROW_PINS { GP13, GP14, GP15, GP16, GP17, GP18, GP19, GP20 }
#define MATRIX_COL_PINS { GP2, GP3, GP4, GP5, GP6, GP7, GP8, GP9, GP10, GP11, GP12 }

#define DIODE_DIRECTION COL2ROW

#define ENCODERS_PAD_A { GP21 }
#define ENCODERS_PAD_B { GP22 }

#define WS2812_DI_PIN GP27
#define RGBLED_NUM 47
#define RGBLIGHT_LIMIT_VAL 120

#define RGB_INDICATOR_PIN GP26
#define RGB_INDICATOR_NUM 14
#define RGB_INDICATOR_LIMIT_VAL 120

#define SDA_PIN GP0
#define SCL_PIN GP1

#define DEBOUNCE 5

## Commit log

2025-02-18 It begins
    Keyboard matrix in place
    [MX_Switch.step, Riptide.kicad_pcb, Riptide.kicad_sch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]
2025-07-31 Finally Done!!
    I have been working on this off and on since the 1st lol
    [BOM.csv, Keyboard Knob.step, OLED_0.91_128x32.stp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]
2025-08-01 Blender Renders
    Blender might be goated
    (First time using it)
    [BOM.csv]
2025-08-01 Fix BOM
    [BOM.csv]
2025-08-09 Quick I2C Fix
    [Riptide-B_Cu.gbr, Riptide-B_Mask.gbr, Riptide-B_Paste.gbr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]
